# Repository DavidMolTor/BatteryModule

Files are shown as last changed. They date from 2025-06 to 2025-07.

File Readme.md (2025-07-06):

# USB-C Battery Module

A compact and reliable power module for battery-powered electronics.

## Introduction

This module is designed to be used in guitars and effect pedals as a rechargeable supply with minimal output voltage ripple.

The module contains a TP4056 charging IC and a voltage regulation stage consisting of a TLV61048 boost converter and a TLV76701 linear regulator for further smoothing of the output voltage.

It is designed for 9V output voltage, although it can be configured by adjusting a couple of resistor dividers. It also has PH connectors for charging, battery and output to be able to adapt it to different use cases.

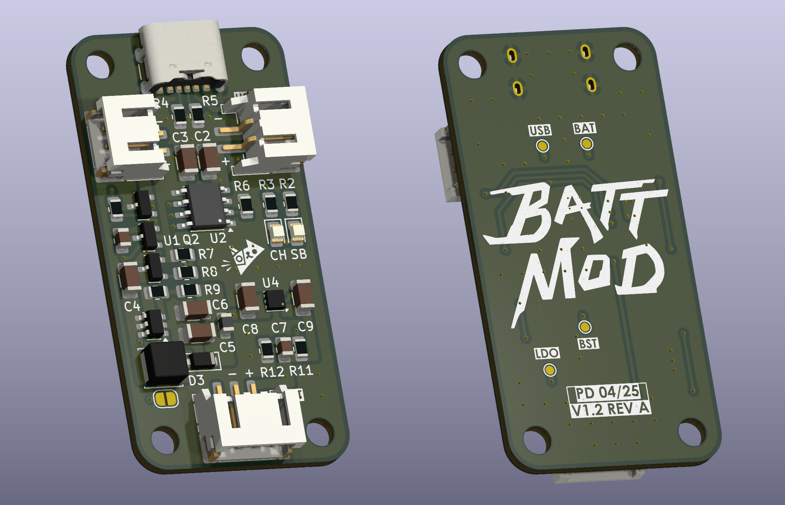
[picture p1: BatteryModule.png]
BATTERY MODULE


## Features

 - Independent voltage monitor for overdischarge control.

 - 9V output configurable via resistor dividers.

 - Available pin for battery disconnection.

 - LED indicators for charging status display.

 - Soldered USB-C connector for charging.

 - PH connectors for battery, charging and output.

 - Large package sizes for easy hand-soldering.

 - Tested continuous 500mA output and 1A charging current.

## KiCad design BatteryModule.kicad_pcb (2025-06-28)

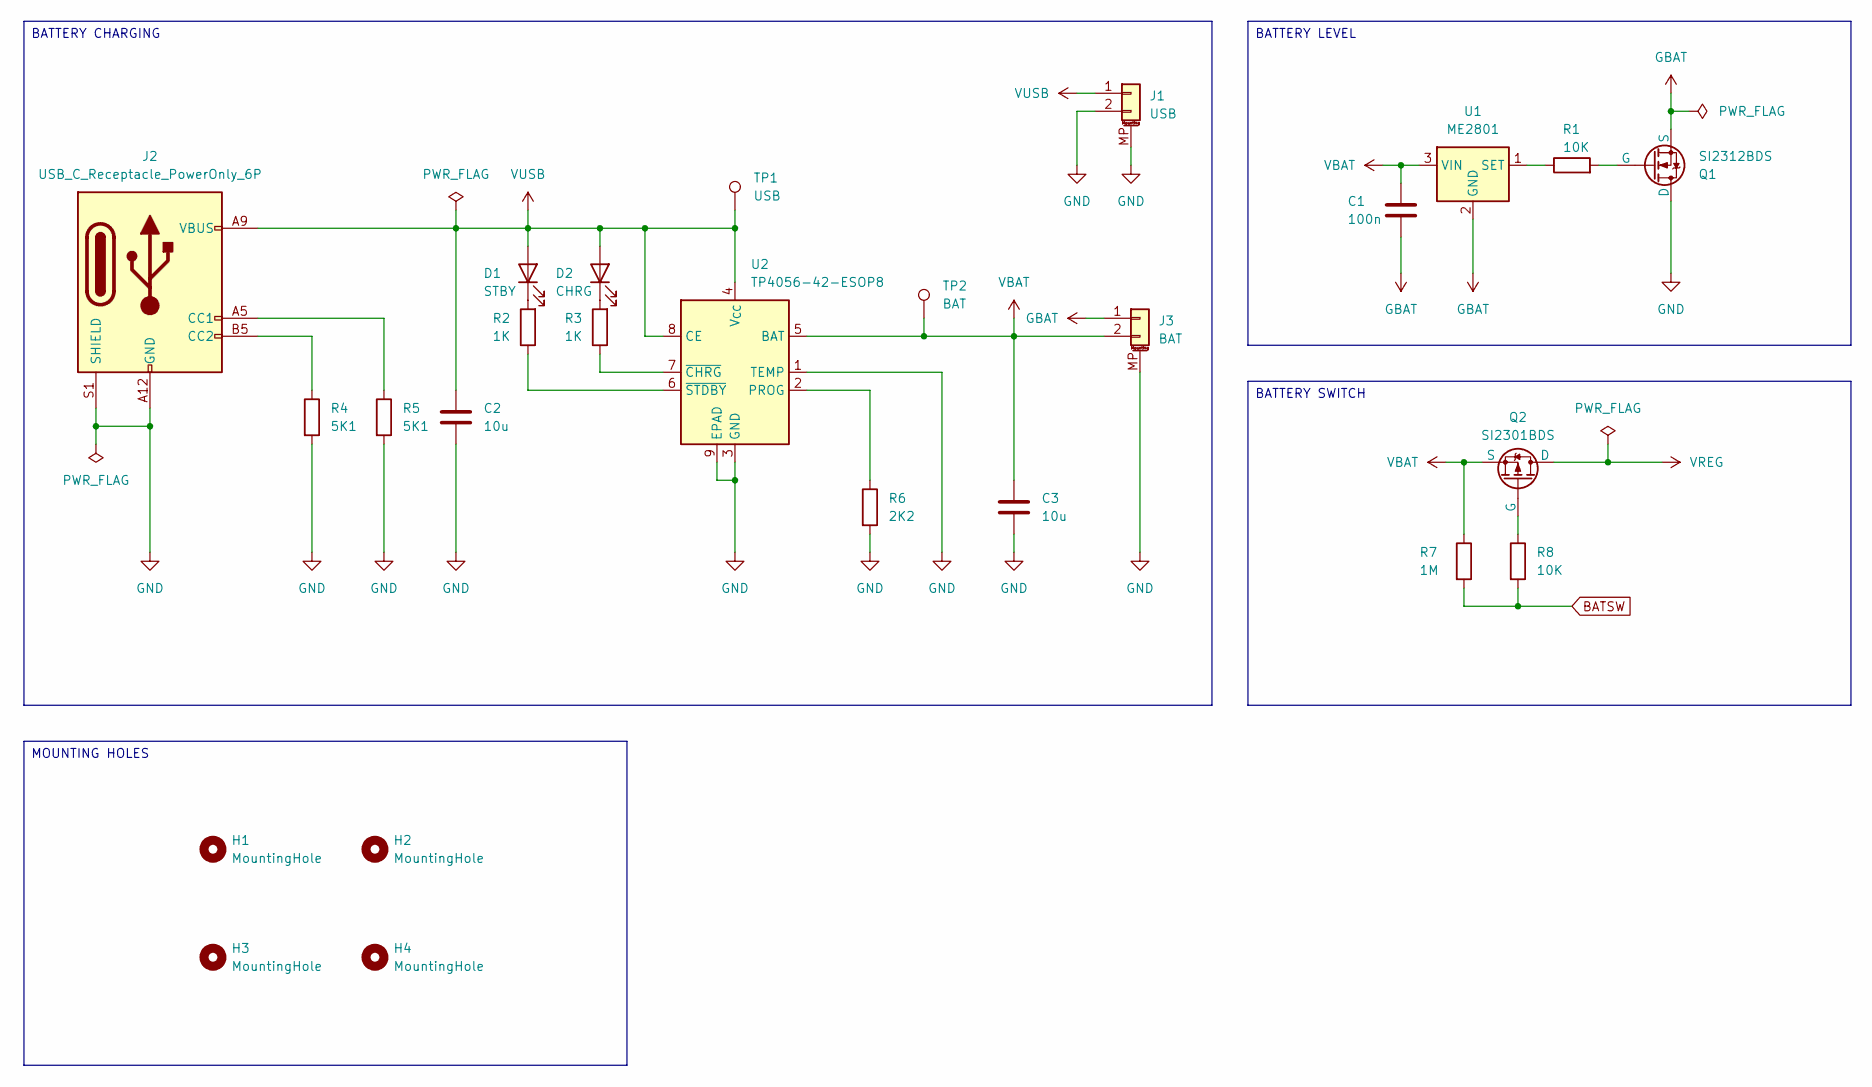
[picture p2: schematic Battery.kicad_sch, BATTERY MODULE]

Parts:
C1: 100n; C_0805_2012Metric
C2, C3: 10u; C_1206_3216Metric
D1: STBY; LED_0805_2012Metric
D2: CHRG; LED_0805_2012Metric
H1, H2, H3, H4: MountingHole; MountingHole_3.2mm_M3
J1: USB; JST_PH_1x02_P2.00MM_SMD_HOR
J2: USB_C_Receptacle_PowerOnly_6P; USB_C_Receptacle_GCT_USB4125-xx-x_6P_TopMnt_Horizontal
J3: BAT; JST_PH_1x02_P2.00MM_SMD_HOR
Q1: SI2312BDS; SOT-23_NO_MARK
Q2: SI2301BDS; SOT-23_NO_MARK
R1, R8: 10K; R_0805_2012Metric
R2, R3: 1K; R_0805_2012Metric
R4, R5: 5K1; R_0805_2012Metric
R6: 2K2; R_0805_2012Metric
R7: 1M; R_0805_2012Metric
TP1: USB; TestPoint_Pad_D1.0mm
TP2: BAT; TestPoint_Pad_D1.0mm
U1: ME2801; SOT-23_NO_MARK
U2: TP4056-42-ESOP8; SOIC-8-1EP_3.9x4.9MM_P1.27MM_EP2.41x3.3MM

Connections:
BATSW: R7.2, R8.2; also elsewhere on the board
GBAT: C1.2, J3.1, Q1.2 (S), U1.2 (GND)
GND: C2.2, C3.2, J1.2, J1.MP (MountPin), J2.A12 (GND), J2.B12 (GND), J2.S1 (SHIELD), J3.MP (MountPin), Q1.3 (D), R4.2, R5.2, R6.2, U2.1 (TEMP), U2.3 (GND), U2.9 (EPAD); also elsewhere on the board
unnamed: D1.1 (K), R2.2
unnamed: D2.1 (K), R3.2
unnamed: J2.A5 (CC1), R5.1
unnamed: J2.B5 (CC2), R4.1
unnamed: Q1.1 (G), R1.2
unnamed: Q2.1 (G), R8.1
unnamed: R1.1, U1.1 (SET)
unnamed: R6.1, U2.2 (PROG)
unnamed: R3.1, U2.7 (~CHRG)
unnamed: R2.1, U2.6 (~STDBY)
VBAT: C1.1, C3.1, J3.2, Q2.2 (S), R7.1, TP2.1, U1.3 (VIN), U2.5 (BAT)
VREG: Q2.3 (D); also elsewhere on the board
VUSB: C2.1, D1.2 (A), D2.2 (A), J1.1, J2.A9 (VBUS), J2.B9 (VBUS), TP1.1, U2.4 (V_{CC}), U2.8 (CE)

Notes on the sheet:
BATTERY LEVEL
MOUNTING HOLES
BATTERY SWITCH
BATTERY CHARGING

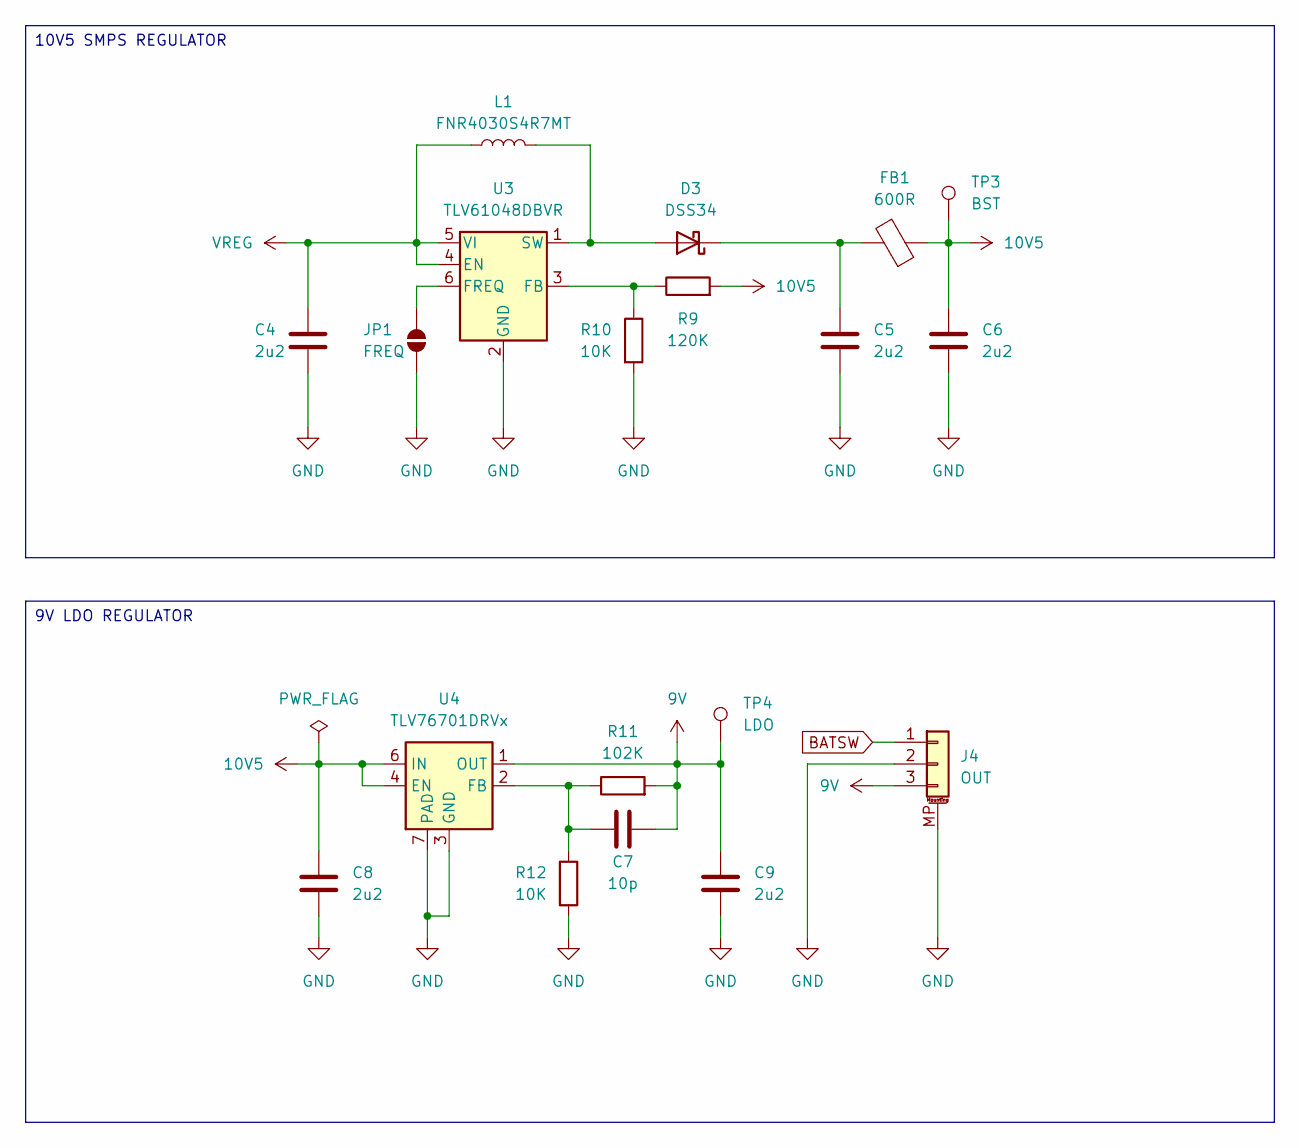
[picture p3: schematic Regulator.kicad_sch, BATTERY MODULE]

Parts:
C4, C5, C6, C8, C9: 2u2; C_1206_3216Metric
C7: 10p; C_0805_2012Metric
D3: DSS34; D_SOD-123F
FB1: 600R; L_0805_2012Metric
J4: OUT; JST_PH_1x03_P2.00MM_SMD_HOR
JP1: FREQ; SolderJumper-2_P1.3mm_Open_RoundedPad1.0x1.5mm
L1: FNR4030S4R7MT; L_Changjiang_FNR4030S
R9: 120K; R_0805_2012Metric
R10, R12: 10K; R_0805_2012Metric
R11: 102K; R_0805_2012Metric
TP3: BST; TestPoint_Pad_D1.0mm
TP4: LDO; TestPoint_Pad_D1.0mm
U3: TLV61048DBVR; SOT-23-6
U4: TLV76701DRVx; WSON-6-1EP_2x2mm_P0.65mm_EP1x1.6mm_ThermalVias

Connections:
9V: C7.2, C9.1, J4.3, R11.2, TP4.1, U4.1 (OUT)
10V5: C6.1, C8.1, FB1.1, R9.2, TP3.1, U4.4 (EN), U4.6 (IN)
BATSW: J4.1; also elsewhere on the board
GND: C4.2, C5.2, C6.2, C8.2, C9.2, J4.2, J4.MP (MountPin), JP1.1 (A), R10.2, R12.2, U3.2 (GND), U4.3 (GND), U4.5 (GND), U4.7 (PAD); also elsewhere on the board
unnamed: D3.2 (A), L1.2, U3.1 (SW)
unnamed: C5.1, D3.1 (K), FB1.2
unnamed: JP1.2 (B), U3.6 (FREQ)
unnamed: R9.1, R10.1, U3.3 (FB)
unnamed: C7.1, R11.1, R12.1, U4.2 (FB)
VREG: C4.1, L1.1, U3.4 (EN), U3.5 (VI); also elsewhere on the board

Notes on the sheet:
10V5 SMPS REGULATOR
9V LDO REGULATOR

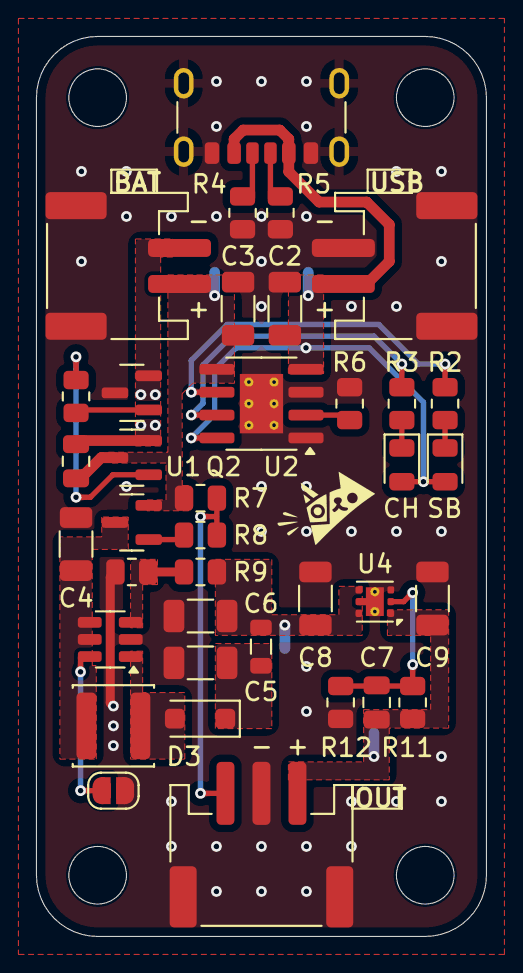
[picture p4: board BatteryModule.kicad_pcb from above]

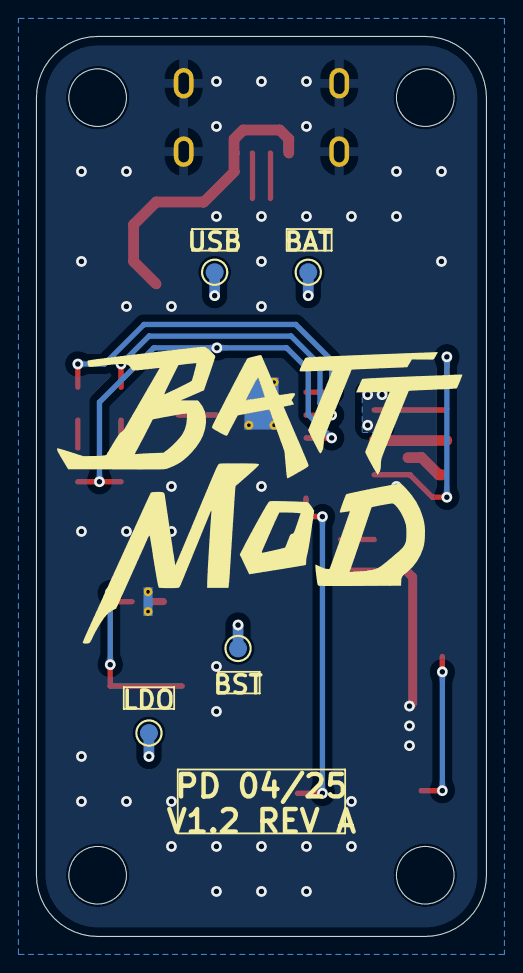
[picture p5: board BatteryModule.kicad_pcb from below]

Board: 2 copper layers, 25.0 x 50.0 mm, 45 parts (4 on the bottom side), 23 nets.

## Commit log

2025-06-28 Initial commit
    Added main project files.
    [BatteryModule.kicad_pcb, BatteryModule.kicad_sch]
2025-06-28 Modified design structure
    Added a battery sheet for the schematic.
    Added a regulator sheet for the schematic.
    Updated board layout.
    [Battery.kicad_sch, BatteryModule.kicad_pcb, BatteryModule.kicad_sch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]
2025-06-28 Schematic and board layout
    Updated the project schematic.
    Updated the board layout.
    [Battery.kicad_sch, BatteryModule.kicad_pcb, BatteryModule.kicad_sch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]
2025-07-06 Board picture
    Added a picture of the board render.
